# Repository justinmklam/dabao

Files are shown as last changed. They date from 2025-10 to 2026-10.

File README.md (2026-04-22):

# dabao

打包 (dǎ bāo or daa2 baau1), which means to take out (food) in Chinese, is a wireless, portable 36-key keyboard with a thumb trackpoint, designed for maximum flexibility and convenience.

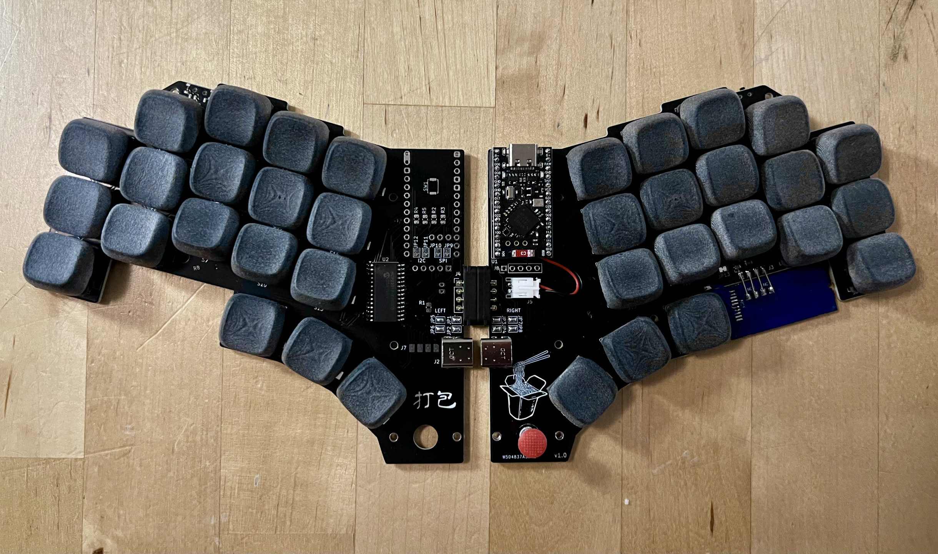
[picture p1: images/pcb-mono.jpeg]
pcb as unibody
> 
> <sub>Keyboard can be used as a unibody...</sub>
>
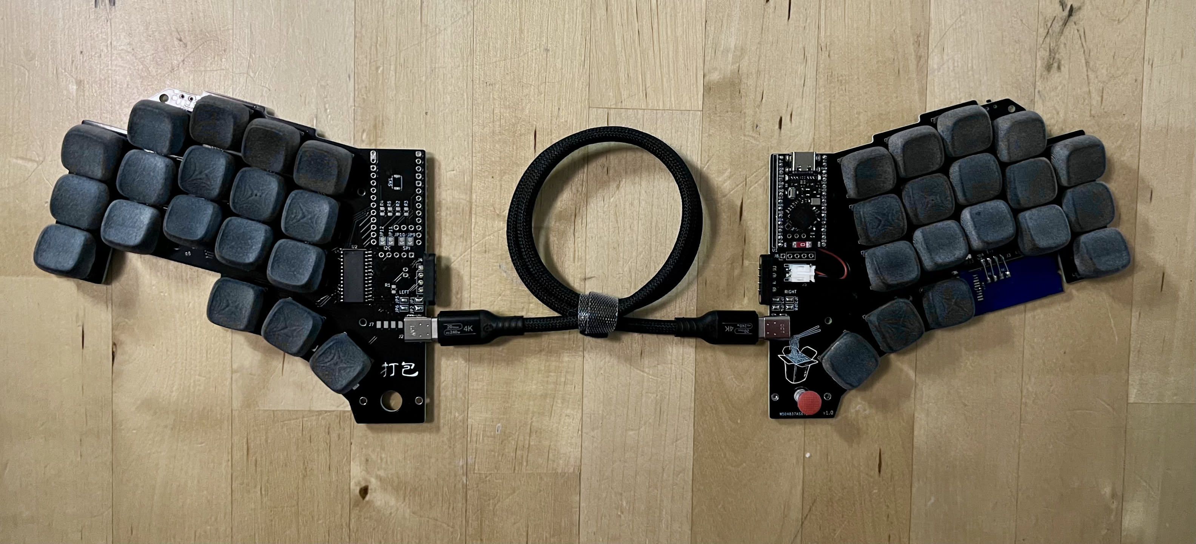
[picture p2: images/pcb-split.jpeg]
pcb as split
> 
> <sub>... or as a split!</sub>

## Design Rationale

I found that split keyboards can be cumbersome when I’m not working at a desk. Managing two independent halves (as well as a laptop) while moving between coworking spaces, cafés, or even working from the couch quickly becomes unwieldy, and I thought there had to be a better way.

This project explores a keyboard that can seamlessly switch between a unibody form factor (easy to pick up and carry) and a fully split configuration when there's space for a full ergonomic setup. An integrated pointing device is included to reduce the need for external peripherals, making it truly portable.

Albeit unconventional, the trackpoint is positioned under the thumb to:

- Enable the use of hotswap sockets while keeping the overall keyboard height low
- Eliminate the need to modify keycaps for trackpoint clearance
- Allow the fingers to remain on the home row during pointing tasks

In practice, using the thumb instead of the index finger feels functionally similar. After a short adjustment period, I personally haven't experienced a meaningful loss in accuracy or precision.

## Features

- **Unibody or Split:** Unique magnetic 4-pin connector allows the keyboard to be used as a single unibody or split into two halves via a USB-C cable. Use unibody mode on the go, and split mode at your desk!
- **Single Microcontroller:** Uses one microcontroller and a GPIO expander, eliminating the need for two controllers or batteries to reduce costs and avoid managing uneven battery discharge.
- **Integrated Trackpoint:** For convenient and precise cursor control.
- **Reversible PCB:** Keeps ordering PCBs affordable. Also enables the trackpoint to be installed on the left or right side.
- **Wireless:** Wireless operation (between the host computer) for portability.
- **Hotswap Switches:** Supports Choc V1 or V2 switches. Can also be soldered directly if desired.

## Firmware

See [zmk-config](https://github.com/justinmklam/zmk-config).

## Case

*Coming soon!* - The case will make the magnetic interface more robust, which will allow the keyboard to be lifted from either side without it collapsing in half. Additional magnets will likely be added to make the connection more secure.

## Build Guide

> [!WARNING]
> This project is provided for educational and experimental purposes only. It is shared "as-is," without any warranty of any kind, express or implied, including but not limited to the warranties of merchantability or fitness for a particular purpose. By using these files, you acknowledge that you are assuming all risks associated with the assembly, use, and operation of the hardware. The author shall not be liable for any claim, damages, or other liability, whether in an action of contract, tort, or otherwise, arising from, out of, or in connection with the project or the use of these files.

*Coming soon!*

## Acknowledgements

This design was inspired by the following keyboards:

- [TPS42](https://github.com/crehmann/TPS42)
- [duet](https://github.com/zzeneg/duet)
- [Santoku](https://www.reddit.com/r/ErgoMechKeyboards/comments/oisnad/i_made_this_santoku_gen_2_trackpoint_as_a/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)

Helpful trackpoint resources:

- [infused-kim's Trackpoint Driver](https://github.com/infused-kim/kb_zmk_ps2_mouse_trackpoint_driver) - outdated for the recent versions of zmk, but still a treasure trove of information
- [Jorne Trackpoint Wiki](https://github.com/joric/jorne/wiki/Tracking)
- [TheMK Wiki - TrackPoint Overview](https://wiki.themk.org/index.php/TrackPoint)
- [KBD News - Trackpoint Integration Guide](https://kbd.news/How-to-integrate-a-trackpoint-into-your-keyboard-2447.html)
- [r/Trackpoint_Builders](https://www.reddit.com/r/TrackPoint_Builders/)
- [Trackpoint Builders Discord](https://discord.gg/48gM4jZkW)

## Support

Thank you to my sponsors for making this project possible!

The PCBs for this project were manufactured by **[PCBWay](https://pcbway.com)**. The boards came out clean with good tolerances and had a fast turnaround, especially considering it came from the other side of the world. Recommended if you're looking to prototype or build your own keyboard!





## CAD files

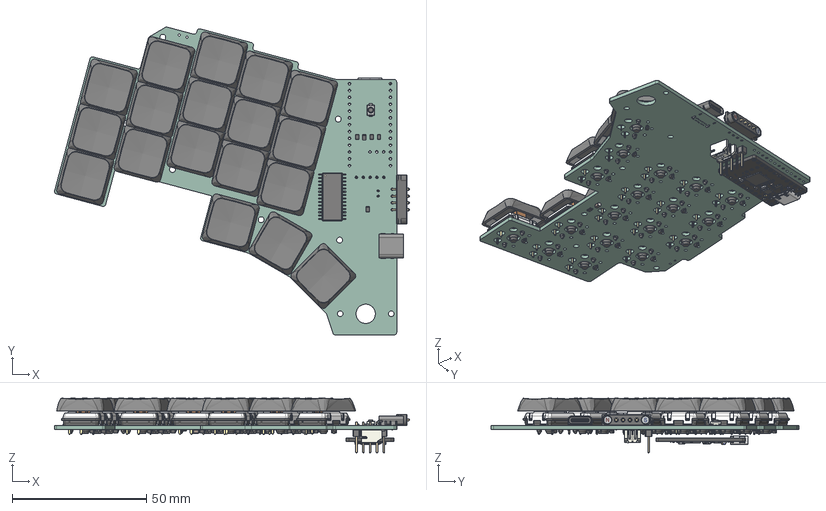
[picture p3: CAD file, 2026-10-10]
pcb/dabao/exports/dabao.step
132.1 x 114.6 x 20.3 mm
R_0805_2012Metric x 6
USB_C_Receptacle_GCT_USB4085
Pin (Type 4)-1-solid1
?????? N-1-solid1
?????? S-1-solid1
Pin (Type 4)-2-solid1
Pin (Type 4)-4-solid1
Pin (Type 4)-5-solid1
SW_Push_SPST_NO_Alps_SKRK
SOIC-28W_7.5x17.9mm_P1.27mm
Document x 108
D_SOD-323 x 18
PinHeader_1x05_P254mm_Vertical
nice!nano v1.0
mcu-chip-ic-2set-leg v1
LED_0603_1608Metric_ON v1
LED_0603_1608Metric_ON v1(Mirror)
Crystal Oscillator v3
Crystal Oscillator v3 (1)
usb4520-03-0-a v1
C0201 v1 x 28
C0402 v1 x 8
0603 v1 x 2
JST_S2B_PH_K
C_0805_2012Metric
dabao_PCB

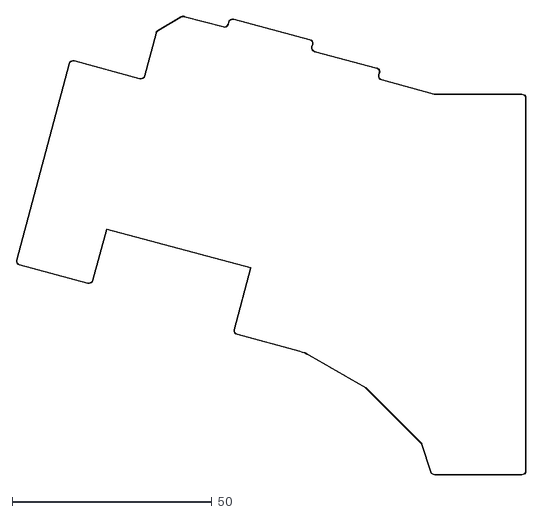
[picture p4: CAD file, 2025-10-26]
pcb/dabao/pcb-outline.dxf
127.5 x 114.6

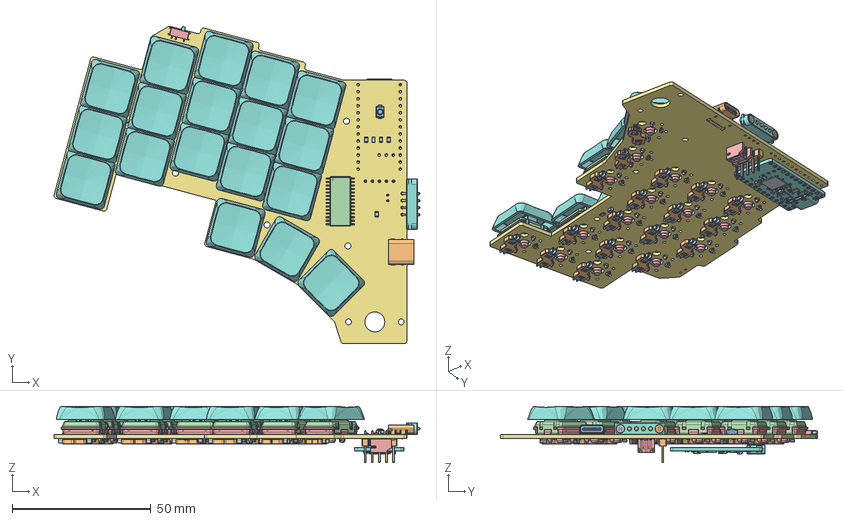
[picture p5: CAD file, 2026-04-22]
pcb/dabao/exports/dabao-left.step
132.1 x 114.6 x 20.3 mm
R_0805_2012Metric x 6
USB_C_Receptacle_GCT_USB4085
Pin (Type 4)-1-solid1
?????? N-1-solid1
?????? S-1-solid1
Pin (Type 4)-2-solid1
Pin (Type 4)-4-solid1
Pin (Type 4)-5-solid1
SW_Push_SPST_NO_Alps_SKRK
SOIC-28W_7.5x17.9mm_P1.27mm
SW_MSK12C02
pin x 36
socket x 18
Document x 90
Kailh Choc FunkMonk 1u x 18
D_SOD-323 x 18
PinHeader_1x05_P2.54mm_Vertical
nice!nano v1.0
mcu-chip-ic-2set-leg v1
LED_0603_1608Metric_ON v1
LED_0603_1608Metric_ON v1(Mirror)
Crystal Oscillator v3
Crystal Oscillator v3 (1)
usb4520-03-0-a v1
C0201 v1 x 28
C0402 v1 x 8
0603 v1 x 2
JST_PH_S2B-PH-K_1x02_P2.00mm_Horizontal
C_0805_2012Metric
dabao_PCB

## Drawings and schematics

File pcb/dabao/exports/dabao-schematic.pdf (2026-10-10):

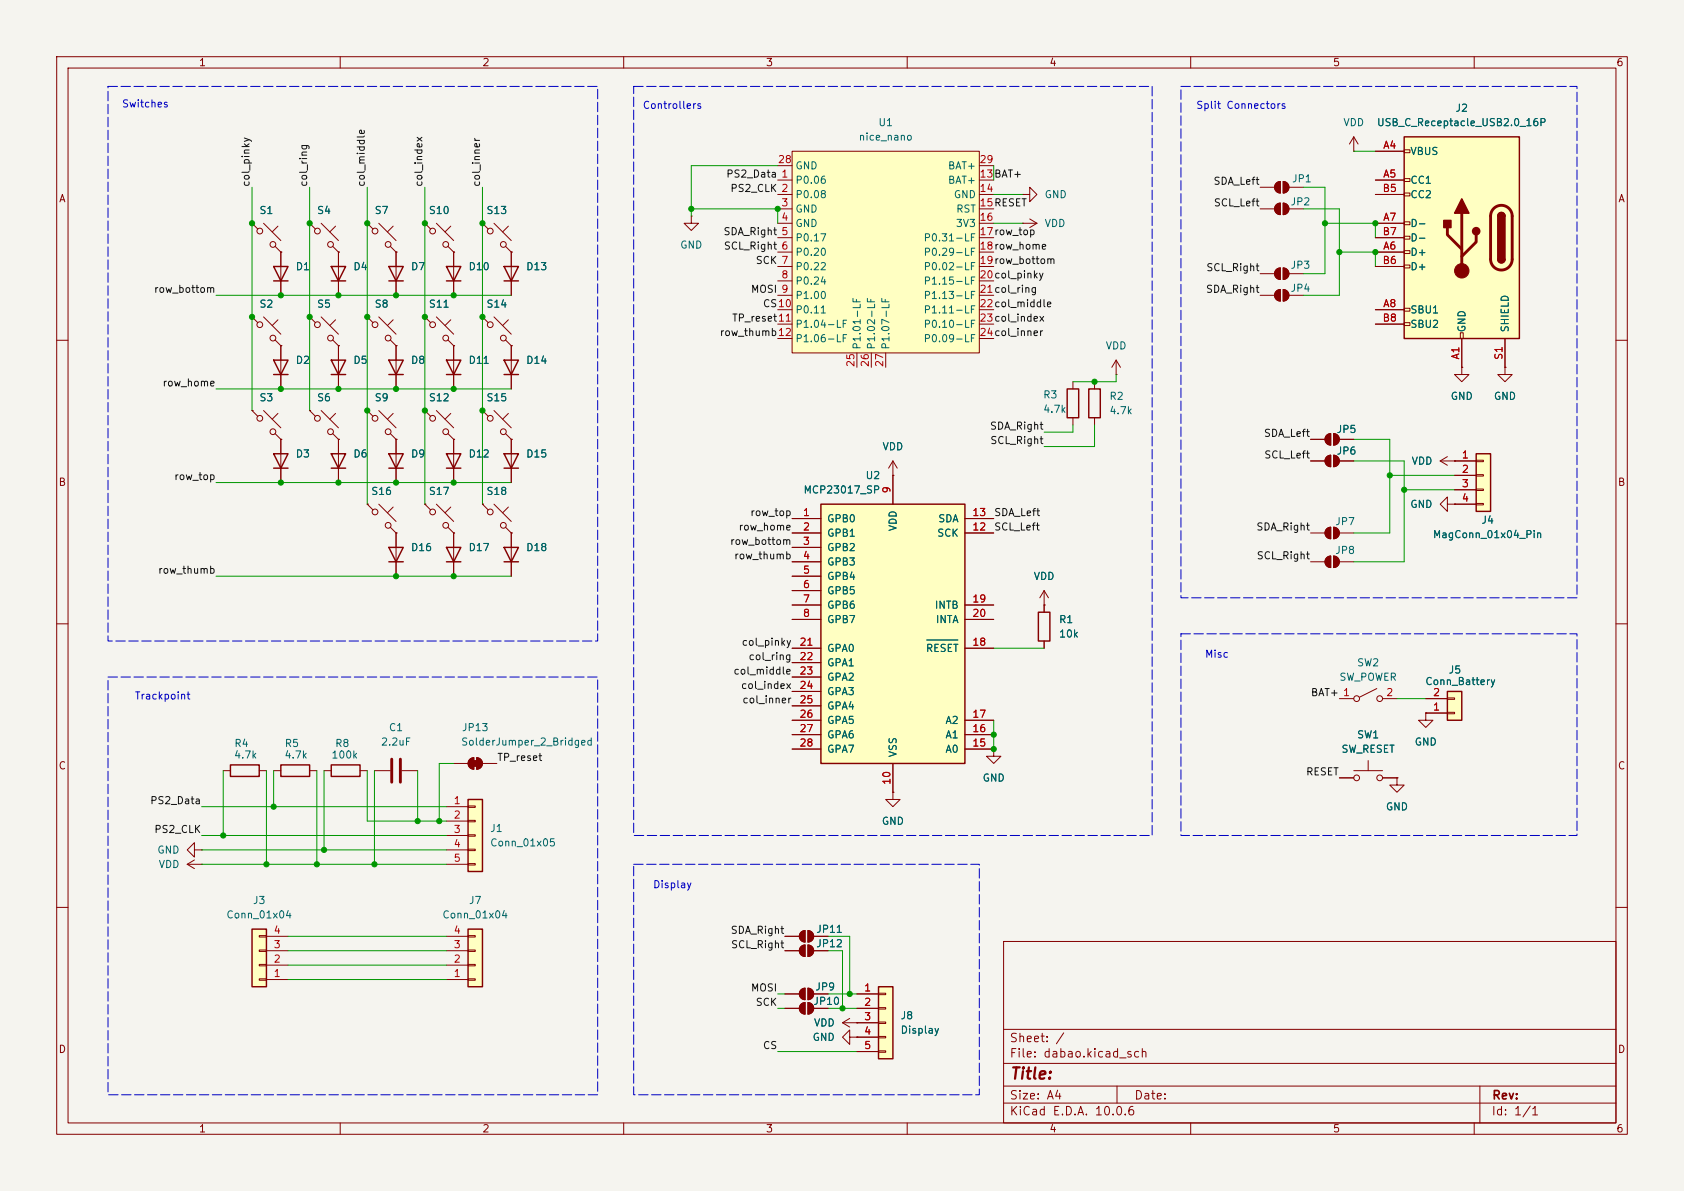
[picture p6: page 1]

Size: A4 | Rev:
KiCad E.D.A. 10.0.6 | Id: 1/1

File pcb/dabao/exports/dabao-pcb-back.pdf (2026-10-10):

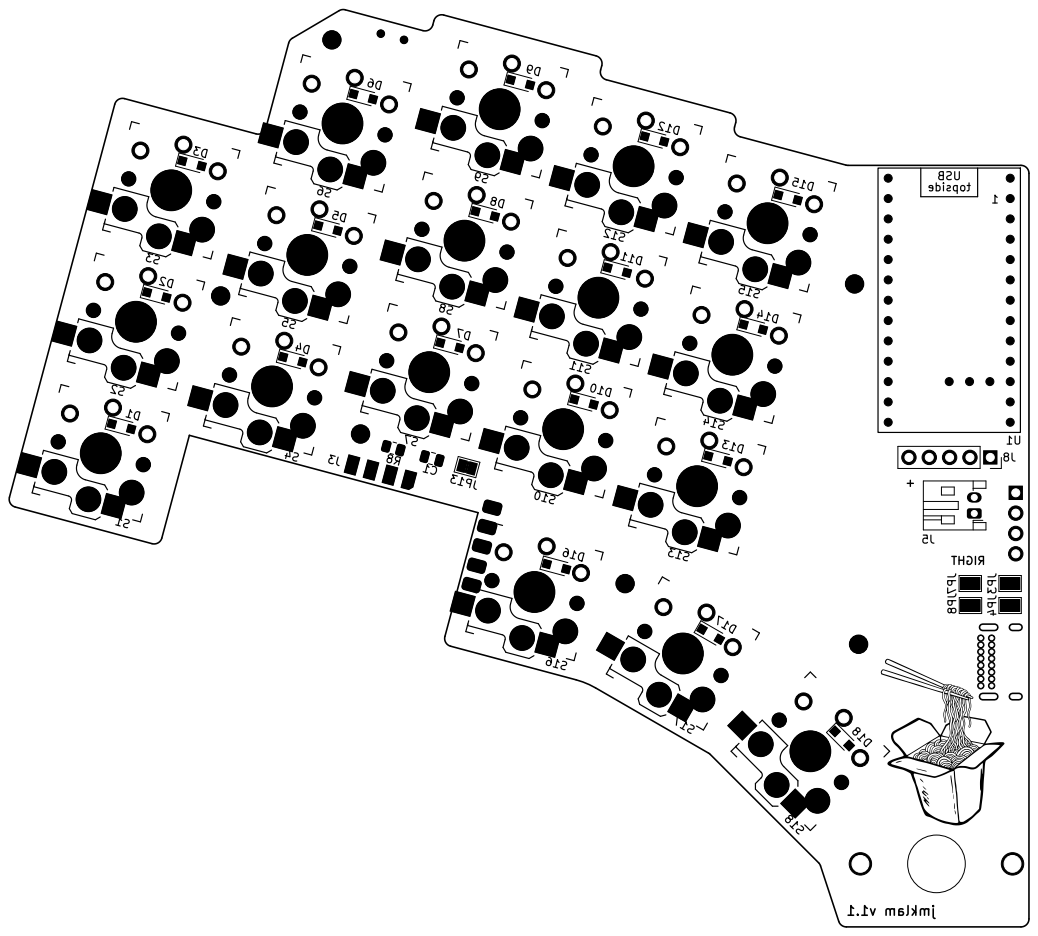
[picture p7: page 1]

Size: A3 | Rev: 1.1 | F Date: 2025-10-08
KiCad E.D.A. 10.0.6 | Id: 1/1

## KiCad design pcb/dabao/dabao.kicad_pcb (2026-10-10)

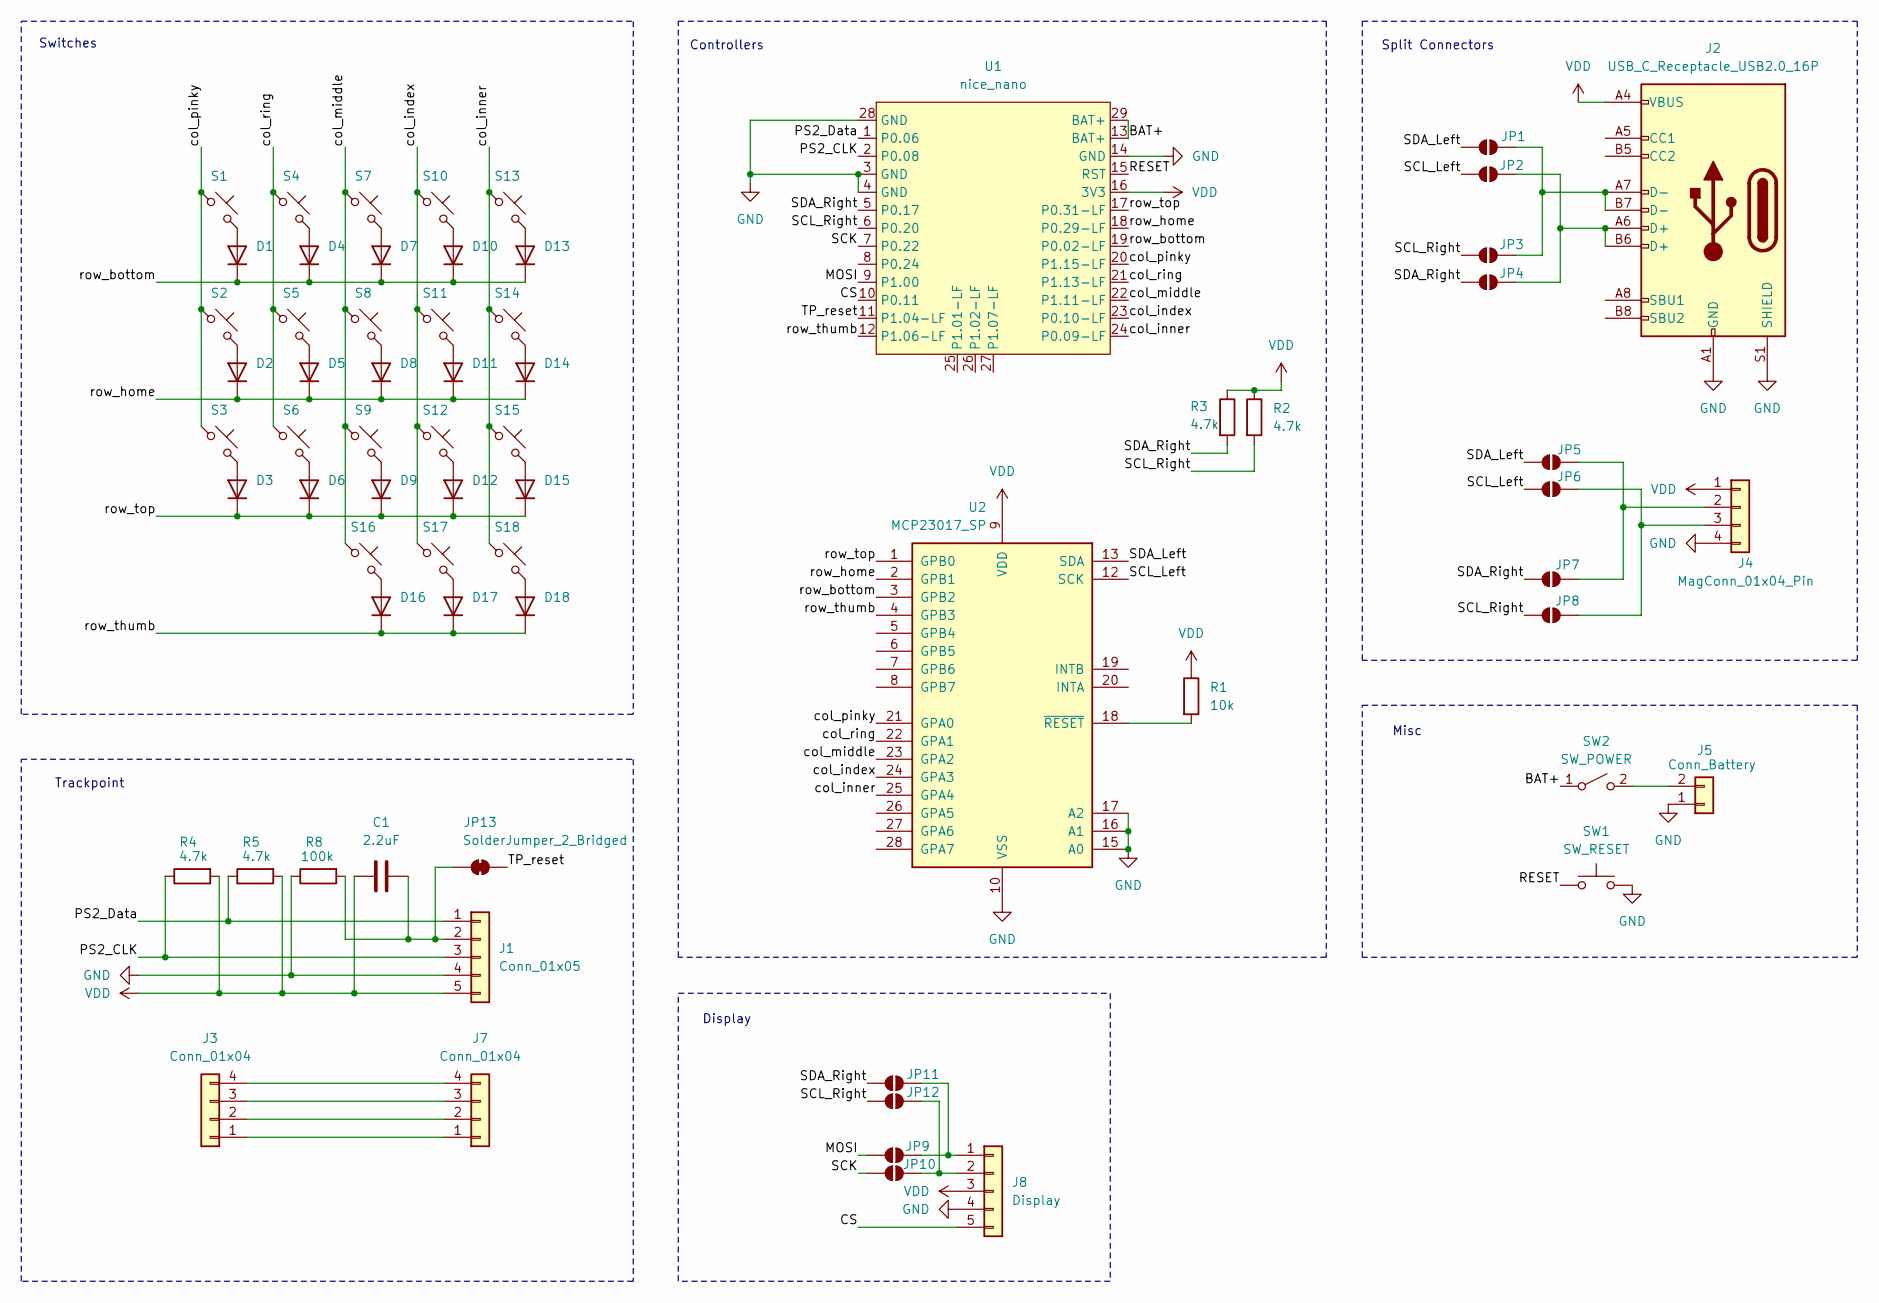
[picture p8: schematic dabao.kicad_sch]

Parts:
C1: 2.2uF; C_0805_2012Metric
D1, D2, D3, D4, D5, D6, D7, D8, D9, D10, D11, D12, D13, D14, D15, D16, D17, D18: 1N4148; D_SOD-323_HandSoldering_Reversable
J1: Conn_01x05; TPModule
J2: USB_C_Receptacle_USB2.0_16P; USB_C_Receptacle_GCT_USB4085
J3, J7: Conn_01x04; TPSensorModule_Connector
J4: MagConn_01x04_Pin; PinMagnetic_1x04_P2.54mm
J5: Conn_Battery; JST_PH_S2B-PH-K_1x02_P2.00mm_Horizontal
J8: Display; PinHeader_1x05_P2.54mm_Vertical
JP1, JP2, JP3, JP4, JP5, JP6, JP7, JP8, JP9, JP10, JP11, JP12: SolderJumper_2_Open; SolderJumper-2_P1.3mm_Open_TrianglePad1.0x1.5mm
JP13: SolderJumper_2_Bridged; SolderJumper-2_P1.3mm_Bridged_Pad1.0x1.5mm
R1: 10k; R_0805_2012Metric
R2, R3, R4, R5: 4.7k; R_0805_2012Metric
R8: 100k; R_0805_2012Metric
S1, S2, S3, S4, S5, S6, S7, S8, S9, S10, S11, S12, S13, S14, S15, S16, S17, S18: choc_v1_SW_HS; Kailh_socket_PG1350_optional_reversible.kicad_mod
SW1: SW_RESET; SW_Push_SPST_NO_Alps_SKRK
SW2: SW_POWER; SW_MSK12C02-HB
U1: nice_nano; nice_nano_AH_USBup
U2: MCP23017_SP; SOIC-28W_7.5x17.9mm_P1.27mm

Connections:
/BAT+: SW2.1 (A), U1.13 (BAT+), U1.29 (BAT+)
/CS: J8.5, U1.10 (P0.11)
/MOSI: JP9.1 (A), U1.9 (P1.00)
/PS2_CLK: J1.3, R4.1, U1.2 (P0.08)
/PS2_Data: J1.1, R5.1, U1.1 (P0.06)
/RESET: SW1.1, U1.15 (RST)
/SCK: JP10.1 (A), U1.7 (P0.22)
/SCL_Left: JP2.1 (A), JP6.1 (A), U2.12 (SCK)
/SCL_Right: JP3.1 (A), JP8.1 (A), JP12.1 (A), R2.2, U1.6 (P0.20)
/SDA_Left: JP1.1 (A), JP5.1 (A), U2.13 (SDA)
/SDA_Right: JP4.1 (A), JP7.1 (A), JP11.1 (A), R3.2, U1.5 (P0.17)
/TP_reset: JP13.2 (B), U1.11 (P1.04-LF)
/col_index: S10.1, S11.1, S12.1, S17.1, U1.23 (P0.10-LF), U2.24 (GPA3)
/col_inner: S13.1, S14.1, S15.1, S18.1, U1.24 (P0.09-LF), U2.25 (GPA4)
/col_middle: S7.1, S8.1, S9.1, S16.1, U1.22 (P1.11-LF), U2.23 (GPA2)
/col_pinky: S1.1, S2.1, S3.1, U1.20 (P1.15-LF), U2.21 (GPA0)
/col_ring: S4.1, S5.1, S6.1, U1.21 (P1.13-LF), U2.22 (GPA1)
/row_bottom: D1.1 (K), D4.1 (K), D7.1 (K), D10.1 (K), D13.1 (K), U1.19 (P0.02-LF), U2.3 (GPB2)
/row_home: D2.1 (K), D5.1 (K), D8.1 (K), D11.1 (K), D14.1 (K), U1.18 (P0.29-LF), U2.2 (GPB1)
/row_thumb: D16.1 (K), D17.1 (K), D18.1 (K), U1.12 (P1.06-LF), U2.4 (GPB3)
/row_top: D3.1 (K), D6.1 (K), D9.1 (K), D12.1 (K), D15.1 (K), U1.17 (P0.31-LF), U2.1 (GPB0)
GND: J1.4, J2.A1 (GND), J2.A12 (GND), J2.B1 (GND), J2.B12 (GND), J2.S1 (SHIELD), J4.4, J5.1, J8.4, R8.1, SW1.2, U1.3 (GND), U1.4 (GND), U1.14 (GND), U1.28 (GND), U2.10 (VSS), U2.15 (A0), U2.16 (A1), U2.17 (A2)
unnamed: D1.2 (A), S1.2
unnamed: D2.2 (A), S2.2
unnamed: D3.2 (A), S3.2
unnamed: D4.2 (A), S4.2
unnamed: D5.2 (A), S5.2
unnamed: D6.2 (A), S6.2
unnamed: D7.2 (A), S7.2
unnamed: D8.2 (A), S8.2
unnamed: D9.2 (A), S9.2
unnamed: D10.2 (A), S10.2
unnamed: D11.2 (A), S11.2
unnamed: D12.2 (A), S12.2
unnamed: D13.2 (A), S13.2
unnamed: D14.2 (A), S14.2
unnamed: D15.2 (A), S15.2
unnamed: D16.2 (A), S16.2
unnamed: D17.2 (A), S17.2
unnamed: D18.2 (A), S18.2
unnamed: C1.2, J1.2, JP13.1 (A), R8.2
unnamed: J3.1, J7.1
unnamed: J3.2, J7.2
unnamed: J3.3, J7.3
unnamed: J3.4, J7.4
unnamed: J4.2, JP5.2 (B), JP7.2 (B)
unnamed: J4.3, JP6.2 (B), JP8.2 (B)
unnamed: J5.2, SW2.2 (B)
unnamed: J8.1, JP9.2 (B), JP11.2 (B)
unnamed: J8.2, JP10.2 (B), JP12.2 (B)
unnamed: J2.A7 (D-), J2.B7 (D-), JP1.2 (B), JP3.2 (B)
unnamed: J2.A6 (D+), J2.B6 (D+), JP2.2 (B), JP4.2 (B)
unnamed: R1.2, U2.18 (~RESET)
VDD: C1.1, J1.5, J2.A4 (VBUS), J2.A9 (VBUS), J2.B4 (VBUS), J2.B9 (VBUS), J4.1, J8.3, R1.1, R2.1, R3.1, R4.2, R5.2, U1.16 (3V3), U2.9 (VDD)

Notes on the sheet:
Misc
Display
Trackpoint
Split Connectors
Controllers
Switches

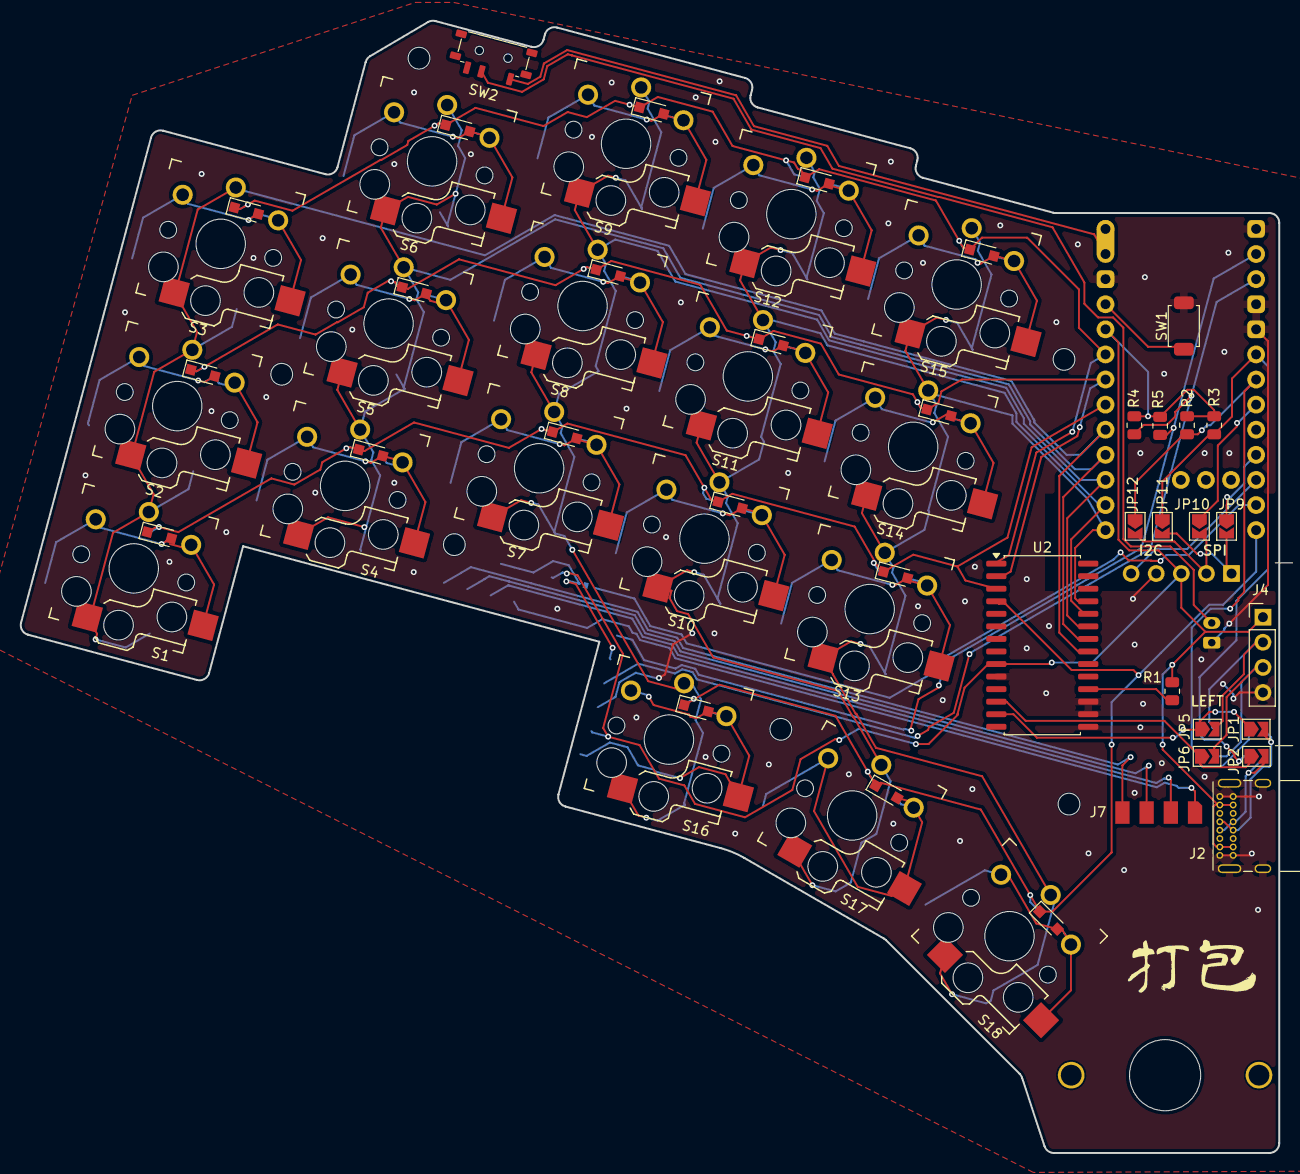
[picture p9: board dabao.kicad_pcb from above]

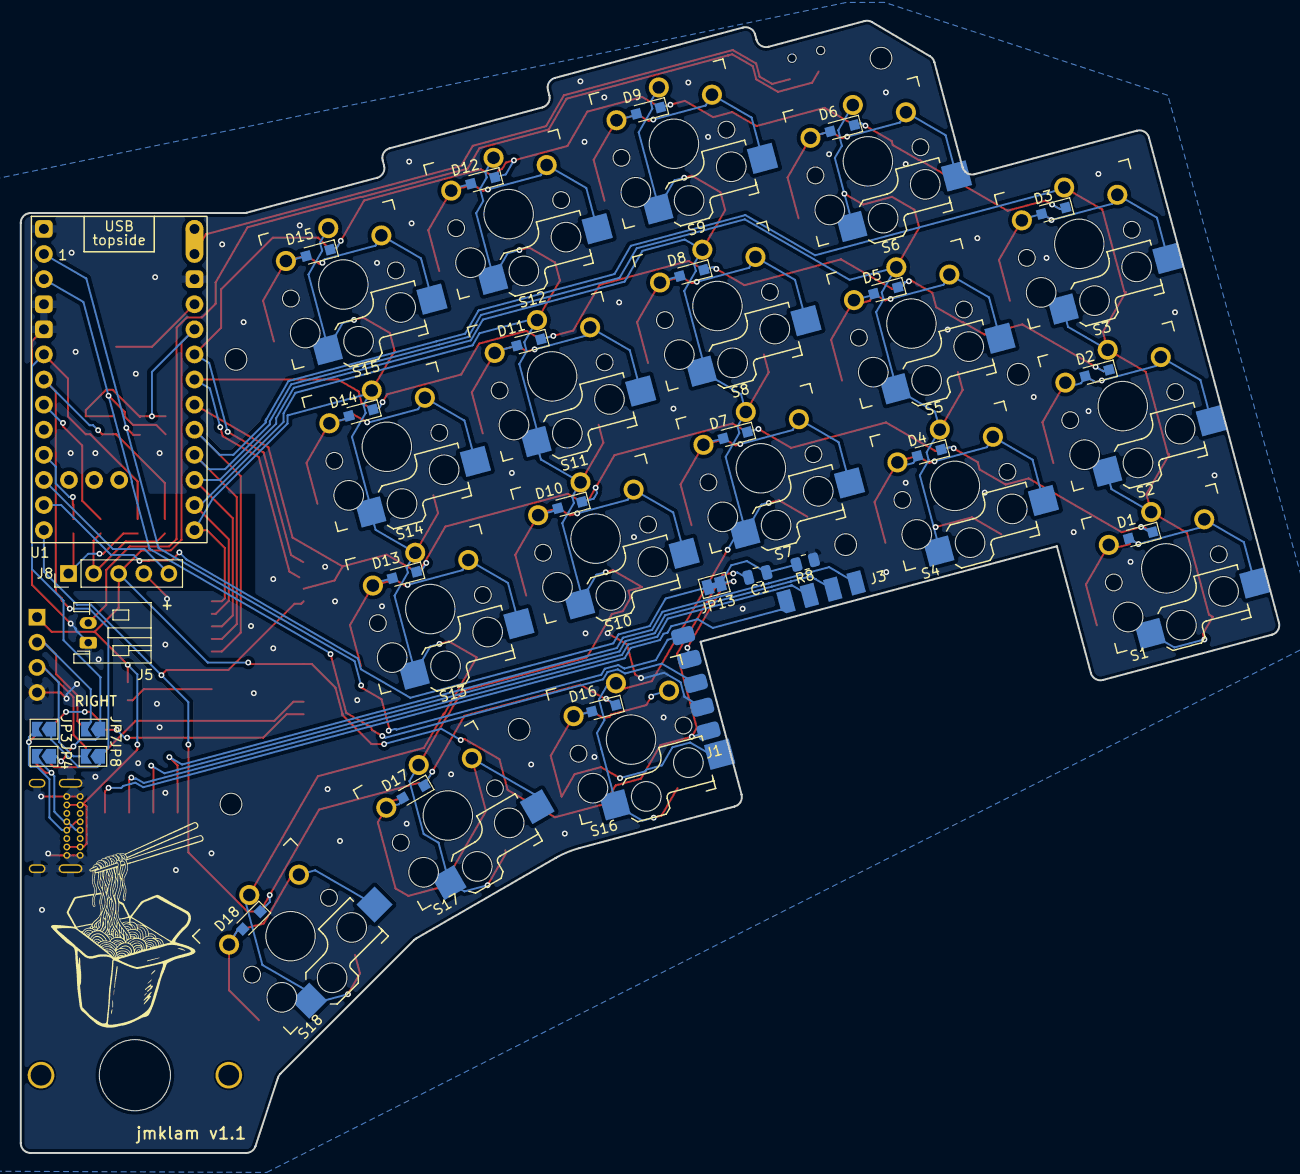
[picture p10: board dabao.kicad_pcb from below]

Board: 2 copper layers, 127.4 x 114.6 mm, 67 parts (48 on the bottom side), 54 nets.

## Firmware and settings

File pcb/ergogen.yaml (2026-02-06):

# Ergogen config file for DaBao keyboard

meta:
  engine: 4.1.0
  version: 1.1
  author: justinmklam

units:
  # Proxy Spacing Variables
  kx: cx
  ky: cy
  # Padding Variables
  px: kx + 2
  py: ky + 2

  split_angle: 15

  # vertical offset of mcu area items
  voff: 11

  # pinky splay angles
  # spang: 8
  spang: 0
  pinksprd: 0.5

  standoff_size: 5 #size for standoff holes on pcb

  hole1_x: -0.5 kx - 1
  hole1_y: -0.5 ky + 0.5

  hole2_x: -0.52 kx
  hole2_y: -0.35 ky

  hole3_x: 0.5 kx + 1
  hole3_y: 0. ky - 1.5

  hole4_x: 0.5 kx - 5
  hole4_y: -0.5 ky - 2.1

  hole5_x: -0.5 kx - 0.4
  hole5_y: -0.2 ky + 1.1

  wall_thickness: 1.2 # account for the thickness in 3D printed case/plate
  print_fit_tolerance: 0.2 # give the case some overlap beyond pcb

  # display correct choc sizing
  $default_width: 18
  $default_height: 17

points:
  zones:
    matrix:
      anchor.shift: [130, -100] # Fix KiCad placement
      key:
        padding: 1ky # is this extra spacing necessary or will 1 allow spacing for keycaps?
        spread: 1kx
      columns:
        # extra: # additional outer key, inspired by TOTEM
        #   rows.bottom.skip: true
        #   rows.top.skip: true
        #   key.splay: spang
        #   key.column_net: col_extra
        pinky:
          key.stagger: 0.33ky
          key.splay: spang # comment this line out if using the 'extra' key above
          key.column_net: col_pinky
        ring:
          key.stagger: 0.8ky
          key.splay: -spang/2
          key.spread: 1kx + pinksprd # avoid collision on splayed col?
          key.column_net: col_ring
        middle:
          key.stagger: 0.4ky
          key.splay: -spang/2
          key.spread: 1kx + pinksprd # avoid collision on splayed col?
          key.column_net: col_middle
        index:
          key.stagger: -0.15ky
          key.column_net: col_index
        inner:
          key.stagger: -0.15ky
          key.column_net: col_inner
      rows:
        bottom:
          row_net: row_bottom
        home:
          row_net: row_home
        top:
          row_net: row_top

    thumb:
      key:
        padding: 1ky
        spread: 1kx
      anchor:
        ref: matrix_index_bottom
        shift: [0.1kx, -1.21ky]
        # rotate: -10
      columns:
        near:
          key.name: thumb_near
          key.column_net: col_middle
        mid:
          key.splay: -15
          key.origin: [-0.5kx, -0.5ky]
          key.name: thumb_mid
          key.column_net: col_index
        far:
          key.splay: -15
          key.origin: [-0.5kx, -0.5ky] #-0.5kx
          key.name: thumb_far
          key.column_net: col_inner
          ## for 1.5 thumb key
          # key.width: 1.5kx
          # key.rotate: 90
      rows:
        thumb-cluster:
          row_net: row_thumb
  rotate: -split_angle
  mirror: &mirror
    ref: thumb_far
    distance: 3.3kx
outlines:
  board_outline:
    - what: polygon
      operation: stack
      points:
        # LEFT SIDE - walk top row (extra column is now the outermost key)
        # - ref: matrix_extra_home
        #   shift: [-0.5px, -0.5py]
        # - ref: matrix_extra_home
        #   shift: [-0.5px, 0.5py]
        - ref: matrix_pinky_top
          shift: [-0.5px, 0.5py]
        - ref: matrix_ring_top
          shift: [-0.5px, 0.5py]
        - ref: matrix_middle_top
          shift: [-0.5px, 0.5py]
        - ref: matrix_middle_top
          shift: [0.5px, 0.5py]
        - ref: matrix_inner_top
          shift: [0.5px, 0.5py]

        # ACROSS TO RIGHT SIDE
        - ref: mirror_matrix_inner_top
          shift: [0.5px, 0.5py]
        - ref: mirror_matrix_middle_top
          shift: [0.5px, 0.5py]
        - ref: mirror_matrix_middle_top
          shift: [-0.5px, 0.5py]
        - ref: mirror_matrix_ring_top
          shift: [-0.5px, 0.5py]
        - ref: mirror_matrix_pinky_top
          shift: [-0.5px, 0.5py]
        # - ref: mirror_matrix_extra_home
        #   shift: [-0.5px, 0.5py]
        # - ref: mirror_matrix_extra_home
        #   shift: [-0.5px, -0.5py]

        # DOWN OUTER EDGE (right half, now extra is outermost)
        - ref: mirror_matrix_pinky_bottom
          shift: [-0.5px, -0.6py]

        # RIGHT THUMB CLUSTER
        - ref: mirror_thumb_near
          shift: [0.5px, -0.5py]
        - ref: mirror_thumb_mid
          shift: [0.5px, -0.5py]
        - ref: mirror_thumb_far
          shift: [0.5px, -0.5py]

        # CROSS UNDER
        - ref: thumb_far
          shift: [0.5px, -0.5py]
        - ref: thumb_mid
          shift: [0.5px, -0.5py]
        - ref: thumb_near
          shift: [-0.5px, -0.5py]

        # LEFT EDGE
        - ref: matrix_pinky_bottom
          shift: [-0.5px, -0.6py]

      fillet: 10
  # just the keys
  raw:
    - what: rectangle
      where: true
      size: [px, py]

  # keys without padding
  keys:
    - what: rectangle
      where: true
      size: [kx-0.5, ky-0.5]
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

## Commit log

2025-10-09 Start of pcb design
    [dabao-choc copy 2.kicad_pcb, dabao-choc copy.kicad_pcb, dabao-choc.kicad_pcb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]
2025-10-09 Add trackpoint parts
    [dabao-choc.kicad_pcb, dabao-choc.kicad_sch]
2025-10-11 Make reversible pcb
    [dabao.kicad_pcb, dabao.kicad_sch]
2025-10-12 Update layout
    [dabao.kicad_pcb, dabao.kicad_sch]
2025-10-12 Clean up schematic
    [dabao.kicad_pcb, dabao.kicad_sch]
2025-10-13 Fix connectors in layout, add board outline, start routing
    [dabao.kicad_pcb, dabao.kicad_sch, pcb-outline.dxf]
2025-10-13 Add missing pullups on ps2 lines
    [dabao.kicad_pcb, dabao.kicad_sch]
2025-10-25 Move trackpoint to thumb, routing
    [dabao.kicad_pcb, dabao.kicad_sch, pcb-outline.dxf]
2025-10-25 Finish routing
    [dabao.kicad_pcb]
2025-10-25 Update routing
    [dabao.kicad_pcb]
2025-10-26 Update pcb outline, final-ish drc checks
    [dabao.kicad_pcb, pcb-outline.dxf]
2025-10-26 Add nets, tweak layout
    [dabao.kicad_pcb, dabao.kicad_sch]
2025-10-29 Add logo, update library path
    [dabao.kicad_pcb]
2025-10-30 Add makefile and kicad export targets
2025-11-22 Updates to models
    [dabao.kicad_pcb]
2026-02-06 Update outline for mounting holes
    [dabao.kicad_pcb, dabao.kicad_sch, pcb-outline.dxf]
2026-02-09 Add case notes and link to infused-kim's driver to README
2026-04-22 Revert "Update outline for mounting holes"
    This reverts commit 8c40ebd10364a523e89f308933ebed6ba8cc3b75.
    [dabao-left.step, dabao-right.step, dabao.kicad_pcb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]
2026-04-22 PCB updates to fix assembly issues
    Addresses https://github.com/justinmklam/dabao/issues/1
    [dabao-left.step, dabao.kicad_pcb, dabao.kicad_sch]
2026-10-09 Revert power switch back to original position, update to kicad 10
    [dabao.kicad_pcb, dabao.kicad_sch]
2026-10-10 Add back mounting hole
    [dabao.kicad_pcb]
2026-10-10 Regenerate pcb exports
    [dabao.step]
